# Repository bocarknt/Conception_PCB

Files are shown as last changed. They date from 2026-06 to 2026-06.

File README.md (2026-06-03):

# Conception PCB – STM32F031K6T7 Système Embarqué

 

Carte PCB personnalisée conçue pour un nœud IoT embarqué basé sur le microcontrôleur **STM32F031K6T7**. Réalisée avec **KiCad** dans le cadre d'un cours de conception de PCB pour systèmes embarqués.

---

## Vue d'ensemble

| Paramètre | Valeur |
|---|---|
| Microcontrôleur | STM32F031K6T7 |
| Dimensions | 53 × 22,5 mm |
| Alimentation | 12V / 5V |
| Tension régulée | 3,3V (régulateur embarqué) |
| Cristal | 8 MHz |

---

## Connecteurs

| Connecteur | Type | Fonction |
|---|---|---|
| J1 | Grove (4 broches) | Capteur – I2C |
| J2 | Header mâle | Communication – UART (FT232) |
| J3 | Header mâle | Programmateur SWD (ST-Link CN4) |
| J4 | Borne à vis | Alimentation (12V / 5V) |

---

## Capteur – SHT31

Capteur de température et d'humidité compatible Grove.

| Paramètre | Valeur |
|---|---|
| Interface | I2C |
| Alimentation | 3,3V |
| Plage de température | -40°C à +125°C |
| Plage d'humidité | 0–100 %HR |

---

## Communication – FT232 (USB-UART)

Le module basé sur le **FT232R** se connecte à **J2** via UART et fournit une interface série USB vers un ordinateur hôte.

| Broche MCU | Signal | Broche J2 |
|---|---|---|
| PA9 (TX) | → RX | FT232 RX |
| PA10 (RX) | ← TX | FT232 TX |
| — | GND | GND |
| — | VCC (3,3V) | VCC |

---

## Programmation – ST-Link via J3 (SWD)

| Broche J3 | Signal | Description |
|---|---|---|
| 1 | VDD_TARGET | 3,3V de la carte |
| 2 | SWCLK | Horloge SWD |
| 3 | GND | Masse |
| 4 | SWDIO | Données SWD |
| 5 | NRST | Réinitialisation |
| 6 | SWO | Réservé |

Outils utilisés : **STM32CubeIDE** + **STM32 ST-Link Utility**

Commande de flashage :
```
-c SWD -p ${project_loc}\Debug\${project_name}.hex -v -Rst
```

---

## Composants embarqués

| Composant | Fonction |
|---|---|
| LED Verte | Sortie numérique (GPIO) |
| RST | Bouton poussoir – Réinitialisation |
| Y1 | Cristal 8 MHz |
| U2 | Régulateur de tension 3,3V |

---

## Structure du dépôt

```
├── README.md
├── kicad/
│   ├── projet.kicad_sch       # Schématique
│   └── projet.kicad_pcb       # Routage PCB
└── media/
    ├── pcb_top.png           # Photo vue dessus
    ├── pcb_bottom.png         # Photo vue dessous
    ├── carte_pcb.jpeg         #photo de la carte avec les composants soudés
    ├── schema.png             #capture du Schématique
    ├── routage.png            # capture du routage
    └── demo.mp4               # Vidéo de démonstration
```

---

## Outils

- [KiCad](https://www.kicad.org/) – Conception schématique et PCB
- [STM32CubeIDE](https://www.st.com/en/development-tools/stm32cubeide.html) – Développement firmware
- [STM32 ST-Link Utility](https://www.st.com/en/development-tools/stsw-link004.html) – Flashage

---

## Références

- [Fiche technique SHT31](https://raw.githubusercontent.com/SeeedDocument/Grove-TempAndHumi_Sensor-SHT31/master/res/Grove-TempAndHumi_Sensor-SHT31-Datasheets.zip)
- [Fiche technique FT232R – FTDI](https://ftdichip.com/wp-content/uploads/2020/08/DS_FT232R.pdf)
- [Fiche technique STM32F031K6 – ST](https://www.st.com/en/microcontrollers-microprocessors/stm32f031k6.html)
- [Connecteur SWD CN4 Nucleo – ST UM1724](https://www.st.com/resource/en/user_manual/um1724-stm32-nucleo64-boards-mb1136-stmicroelectronics.pdf)

---

## Photos de la carte

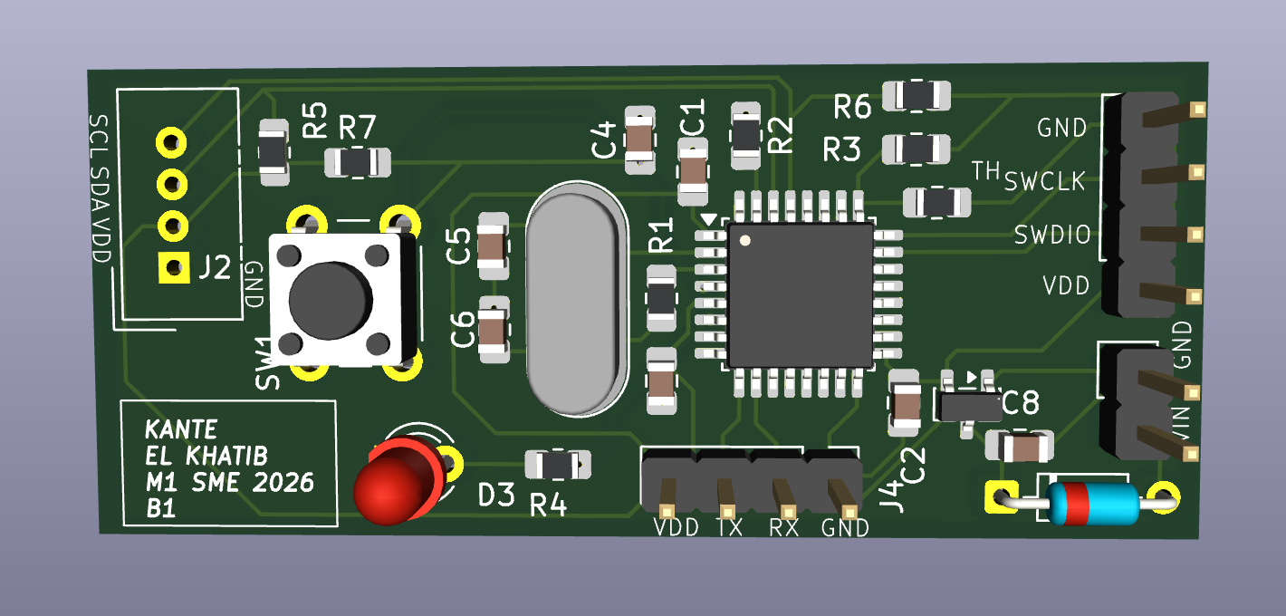
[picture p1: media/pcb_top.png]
Vue dessus

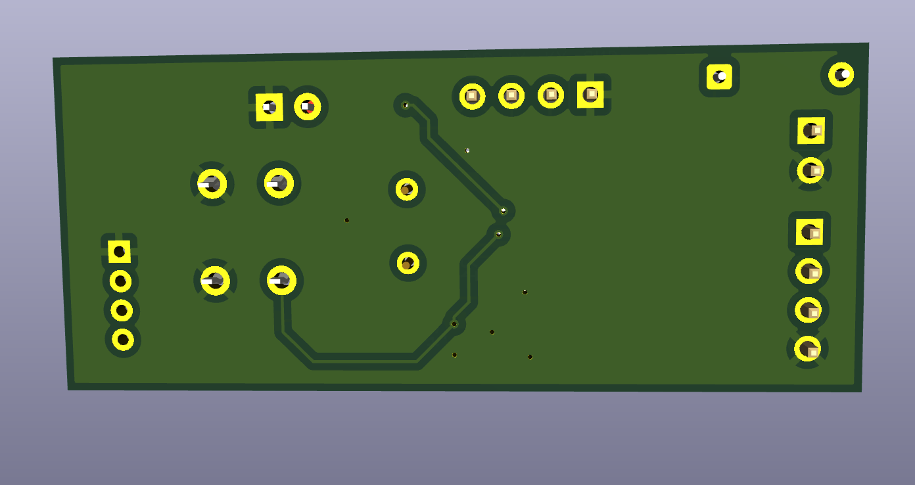
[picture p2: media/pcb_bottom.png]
Vue dessous

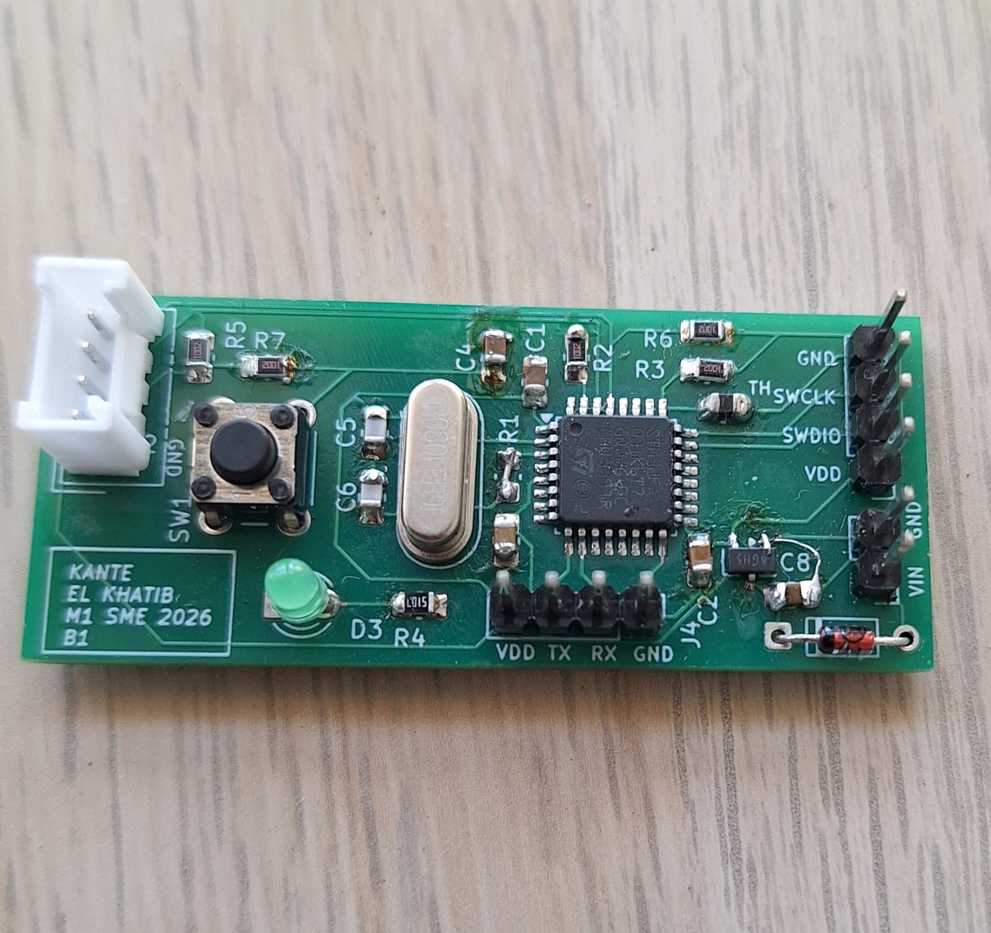
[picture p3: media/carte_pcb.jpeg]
Carte prete


---

## Démonstration

https://github.com/bocarknt/Conception_PCB/blob/main/media/demo.mp4

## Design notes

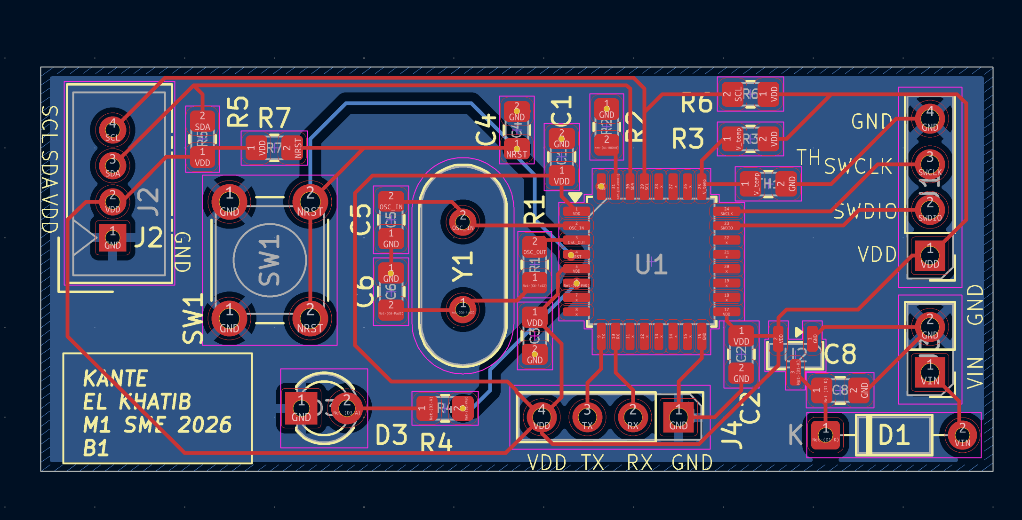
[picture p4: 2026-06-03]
media/routage.png

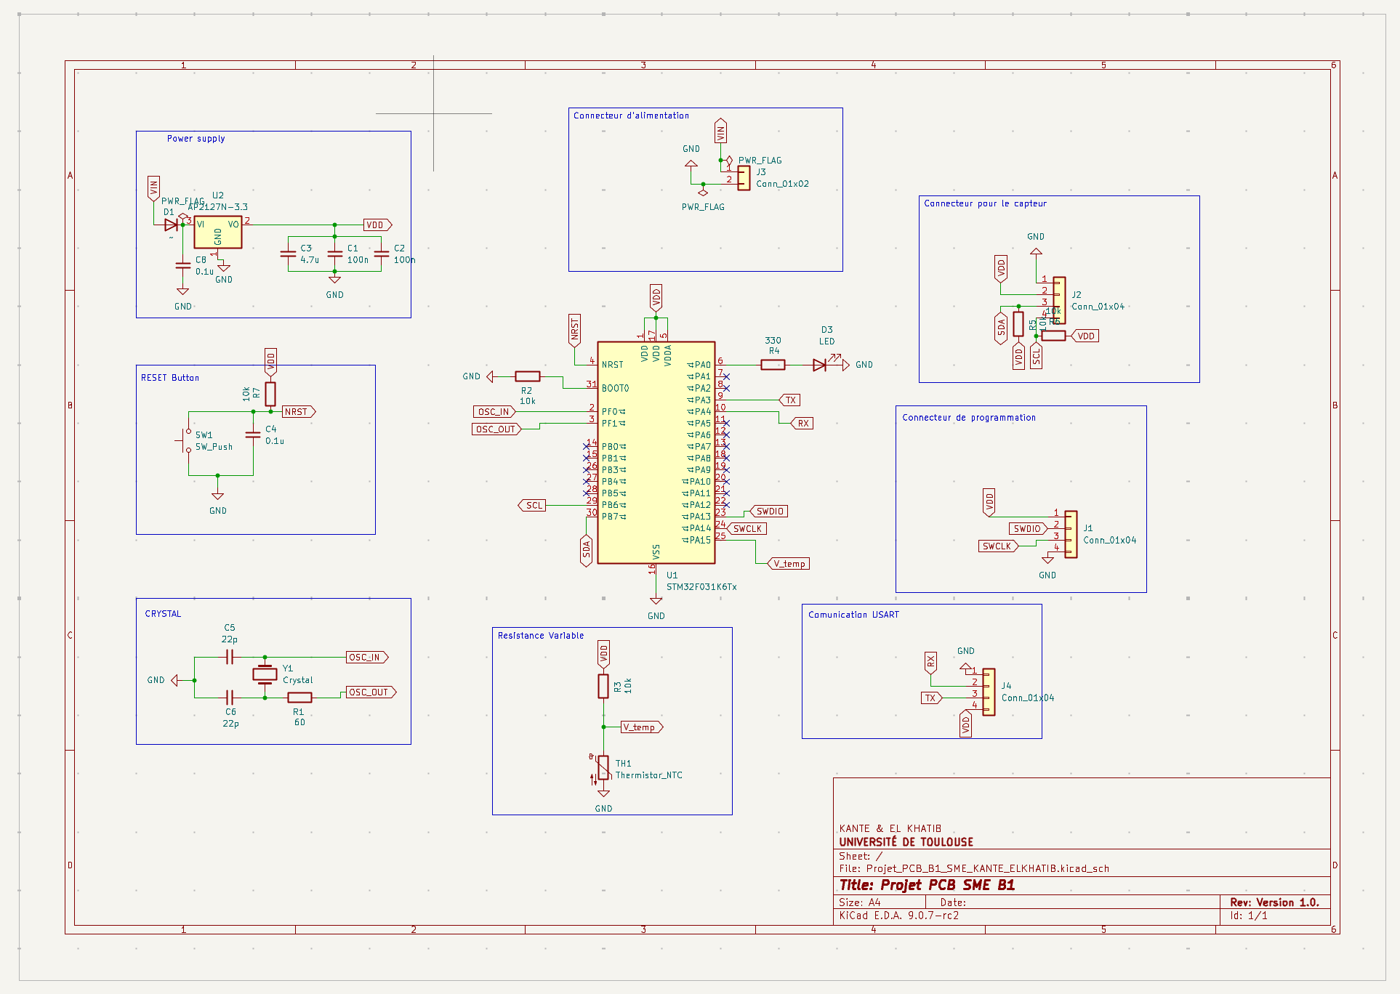
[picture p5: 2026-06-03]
media/schema.png

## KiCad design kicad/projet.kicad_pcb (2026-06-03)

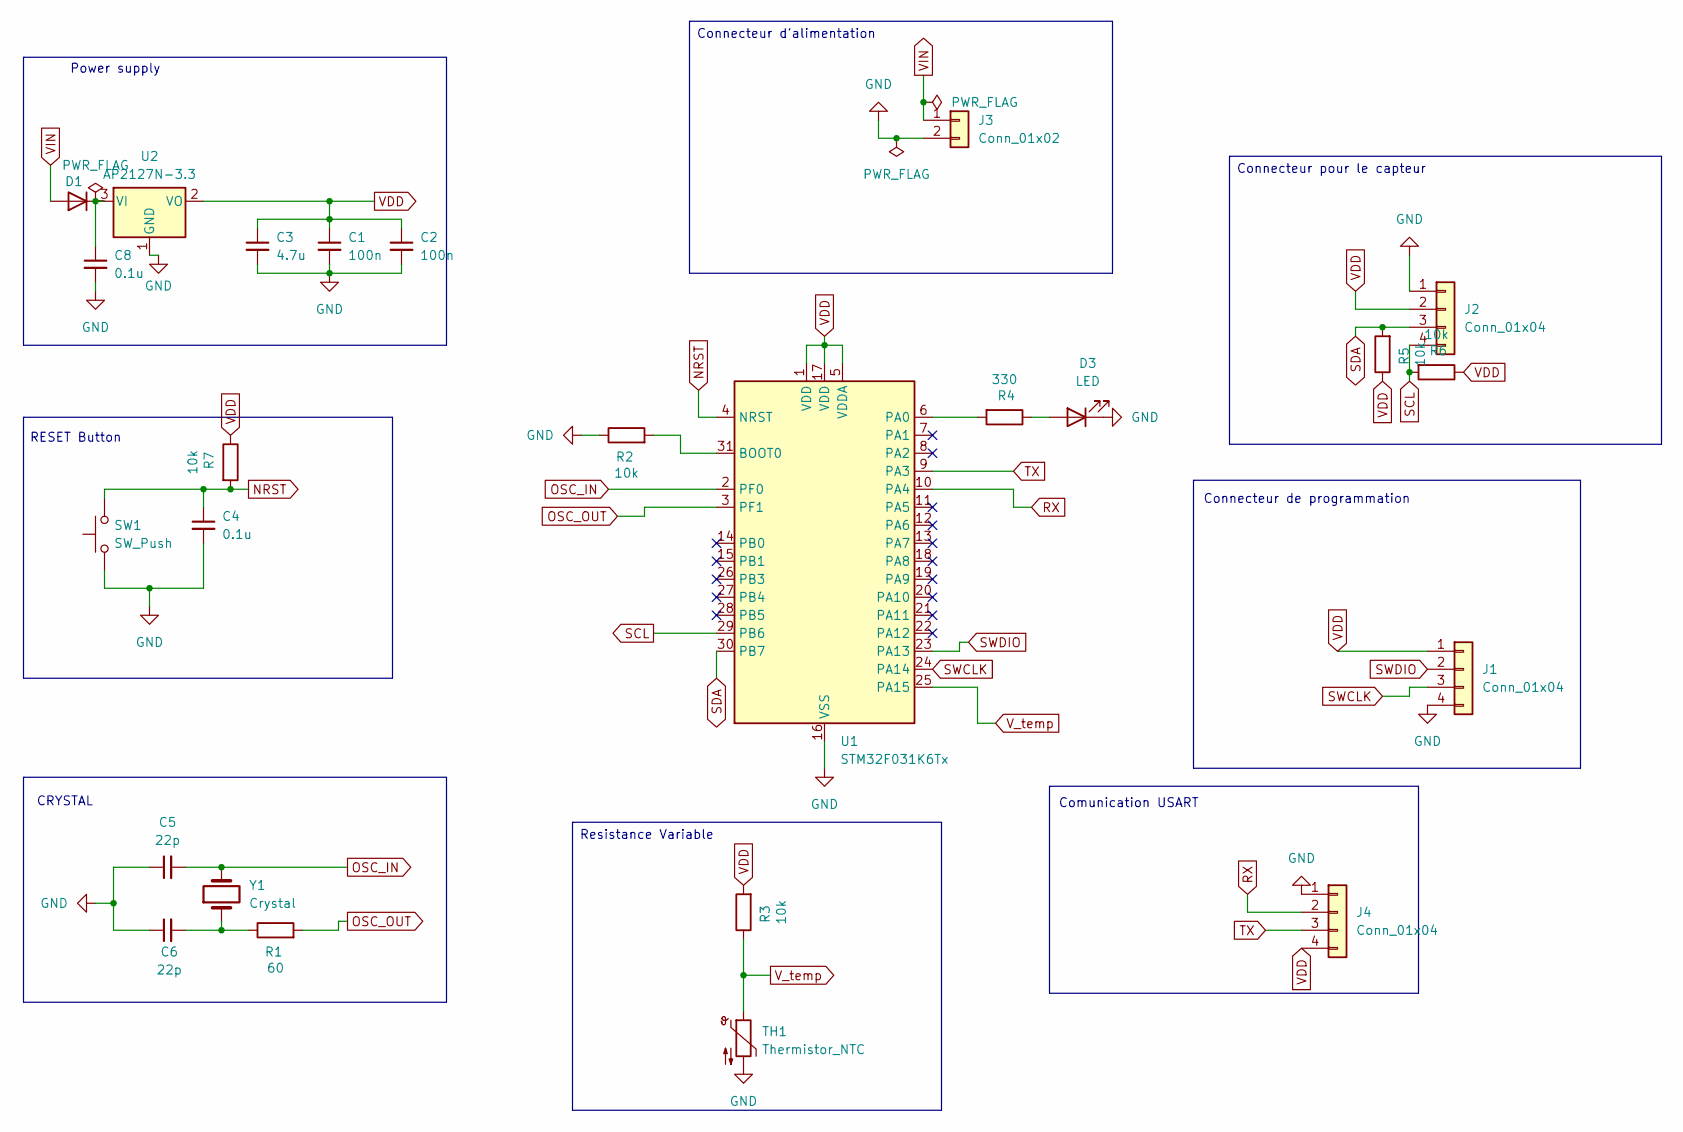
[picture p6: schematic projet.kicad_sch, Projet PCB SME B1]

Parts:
C1, C2: 100n; C_0805_2012Metric_Pad1.18x1.45mm_HandSolder
C3: 4.7u; C_0805_2012Metric_Pad1.18x1.45mm_HandSolder
C4, C8: 0.1u; C_0805_2012Metric_Pad1.18x1.45mm_HandSolder
C5, C6: 22p; C_0805_2012Metric_Pad1.18x1.45mm_HandSolder
D1: D_DO-35_SOD27_P7.62mm_Horizontal
D3: LED; LED_D3.0mm
J1, J4: Conn_01x04; PinHeader_1x04_P2.54mm_Vertical
J2: Conn_01x04; NS-Tech_Grove_1x04_P2mm_Vertical
J3: Conn_01x02; PinHeader_1x02_P2.54mm_Vertical
R1: 60; R_0805_2012Metric_Pad1.20x1.40mm_HandSolder
R2, R3, R5, R6, R7: 10k; R_0805_2012Metric_Pad1.20x1.40mm_HandSolder
R4: 330; R_0805_2012Metric_Pad1.20x1.40mm_HandSolder
SW1: SW_Push; SW_PUSH_6mm_H5mm
TH1: Thermistor_NTC; R_0805_2012Metric_Pad1.20x1.40mm_HandSolder
U1: STM32F031K6Tx; LQFP-32_7x7mm_P0.8mm
U2: AP2127N-3.3; SOT-23
Y1: Crystal; Crystal_HC49-4H_Vertical

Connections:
GND: C1.2, C2.2, C3.2, C4.2, C5.1, C6.1, C8.2, D3.1 (K), J1.4, J2.1, J3.2, J4.1, R2.1, SW1.1, TH1.2, U1.16 (VSS), U1.32 (VSS), U2.1 (GND)
NRST: C4.1, R7.2, SW1.2, U1.4 (NRST)
unnamed: C6.2, R1.1, Y1.1
unnamed: C8.1, D1.1 (K), U2.3 (VI)
unnamed: D3.2 (A), R4.1
unnamed: R2.2, U1.31 (BOOT0)
unnamed: R4.2, U1.6 (PA0)
OSC_IN: C5.2, U1.2 (PF0), Y1.2
OSC_OUT: R1.2, U1.3 (PF1)
RX: J4.2, U1.10 (PA4)
SCL: J2.4, R6.2, U1.29 (PB6)
SDA: J2.3, R5.2, U1.30 (PB7)
SWCLK: J1.3, U1.24 (PA14)
SWDIO: J1.2, U1.23 (PA13)
TX: J4.3, U1.9 (PA3)
VDD: C1.1, C2.1, C3.1, J1.1, J2.2, J4.4, R3.2, R5.1, R6.1, R7.1, U1.1 (VDD), U1.5 (VDDA), U1.17 (VDD), U2.2 (VO)
VIN: D1.2 (A), J3.1
V_temp: R3.1, TH1.1, U1.25 (PA15)

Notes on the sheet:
Connecteur de programmation
RESET Button
Power supply
CRYSTAL
Comunication USART
Connecteur d'alimentation
Resistance Variable
Connecteur pour le capteur

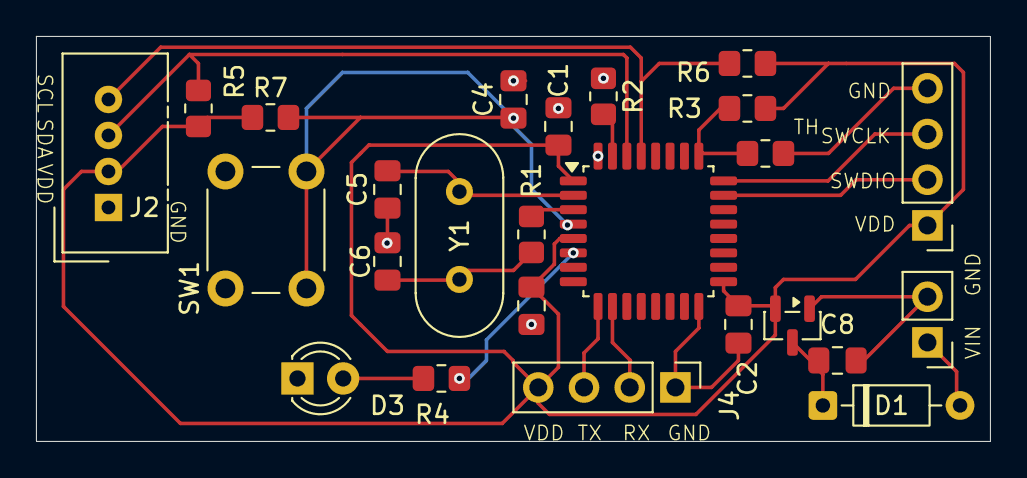
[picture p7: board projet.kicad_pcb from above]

Board: 2 copper layers, 53.0 x 22.5 mm, 25 parts (0 on the bottom side), 18 nets.

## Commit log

2026-06-03 Mise à jour
    [projet.kicad_pcb, projet.kicad_sch]
2026-06-03 Update KiCad version in README
